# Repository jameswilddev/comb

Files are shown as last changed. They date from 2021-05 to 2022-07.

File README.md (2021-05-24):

# Comb

A low parts, low cost, low complexity game board compatible with some arcade cabinets.  So named as the PCB somewhat resembles a comb.

## Contents

- [Comb Arcade Breakout Board](./src/comb-arcade-breakout-board/readme.md) - A simple PCB which breaks the arcade connector out to 2.54mm pin headers or sockets, for prototyping purposes.
- [Comb Board](./src/comb-board/readme.md) - A game PCB which fits directly into the arcade connector.
- [Engine][./src/engine/readme.md] - A simplistic games engine.
- [Games][./src/games/readme.md] - A collection of small example games.

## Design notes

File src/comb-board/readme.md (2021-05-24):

# [Comb](../../README.md) > Board

This is a game PCB which fits directly into the arcade connector.

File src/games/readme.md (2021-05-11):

# [Comb](../../README.md) > Games

This is a collection of small example games.

## Contents

- [Deathmatch Tennis](./deathmatch-tennis/readme.md) - A silly tennis game.

## File Structure

### configuration.asm

Use this file to override any default configuration set by the engine, such as [timings](../engine/timings/defaults.asm) or [pin mappings](../engine/pin-mappings/defaults.asm).

### declarations.asm

Use this file to declare any macros or constants which will be needed in your event handlers.

### on/reset.asm

Executed during start-up.  Initialize any SRAM containing game state here.

### on/frame.asm

Executed once per frame.  Advance game state here.  All registers are to be considered clobbered.  Stability problems may occur should an excessive amount of time be taken (TODO: how many cycles?).

### on/row.asm

Executed once per display row.  All registers are to be considered clobbered.  Configure registers so that the [blitter](../engine/interrupt/handler/active-video.asm) can output pixel data during the next active video region.  Stability problems may occur should an excessive amount of time be taken (TODO: how many cycles?).

### on/sample.asm

Executed at approximately 15kHz (may occur during an interrupt during the frame event handler).  Output the next audio sample.  Stability problems may occur should an excessive amount of time be taken (TODO: how many cycles?).

### data.asm

Use this file to declare any static data which should be included in program memory.  This will be included at the end of the binary.

## Building

To build these games, use Make:

```
make dist/deathmatch-tennis.hex
```

### Dependencies

- A Unix-like environment.
- Make.
- AVRA on the PATH.
- Aseprite on the PATH.
- NodeJS 14.x or newer.

## Deployment

The Makefile also includes some helper targets for configuring the ATMega328P.  These are only intended to be used with a SPI programmer directly connected to the ATMega328P.  An Arduino can be used as a programmer if the ArduinoISP sketch is uploaded to it; check the sketch's documentation for details on connecting the Arduino to the ATMega328P.

### Setting fuses

To set the fuses:

```
make set-fuses PROGRAMMER=avrisp BAUD=19200 PART=M328P PORT=/dev/ttyS3
```

Ensure that a 16mHz crystal is connected with load capacitors first as the fuse configuration will switch from the internal RC oscillator to a crystal oscillator; which will cause it to lock up if no such crystal is attached.

### Flashing a game

To flash a game:

```
make deploy-deathmatch-tennis PROGRAMMER=avrisp BAUD=19200 PART=M328P PORT=/dev/ttyS3
```

### Dependencies

- A Unix-like environment.
- Make.
- AVRDUDE on the PATH.

### Electrical considerations

The default pin mapping avoids using the SPI pins for inputs as activating an arcade input connects it directly to ground - which could damage the ATMega328P and/or the connected programmer.  Conveniently, the SPI pins overlap with the pins needed for video output, which does not pose such a short circuit hazard.

If a bootloader is used, PD0/PD1 will be used instead (TX/RX).  Do not short these pins to ground during programming.

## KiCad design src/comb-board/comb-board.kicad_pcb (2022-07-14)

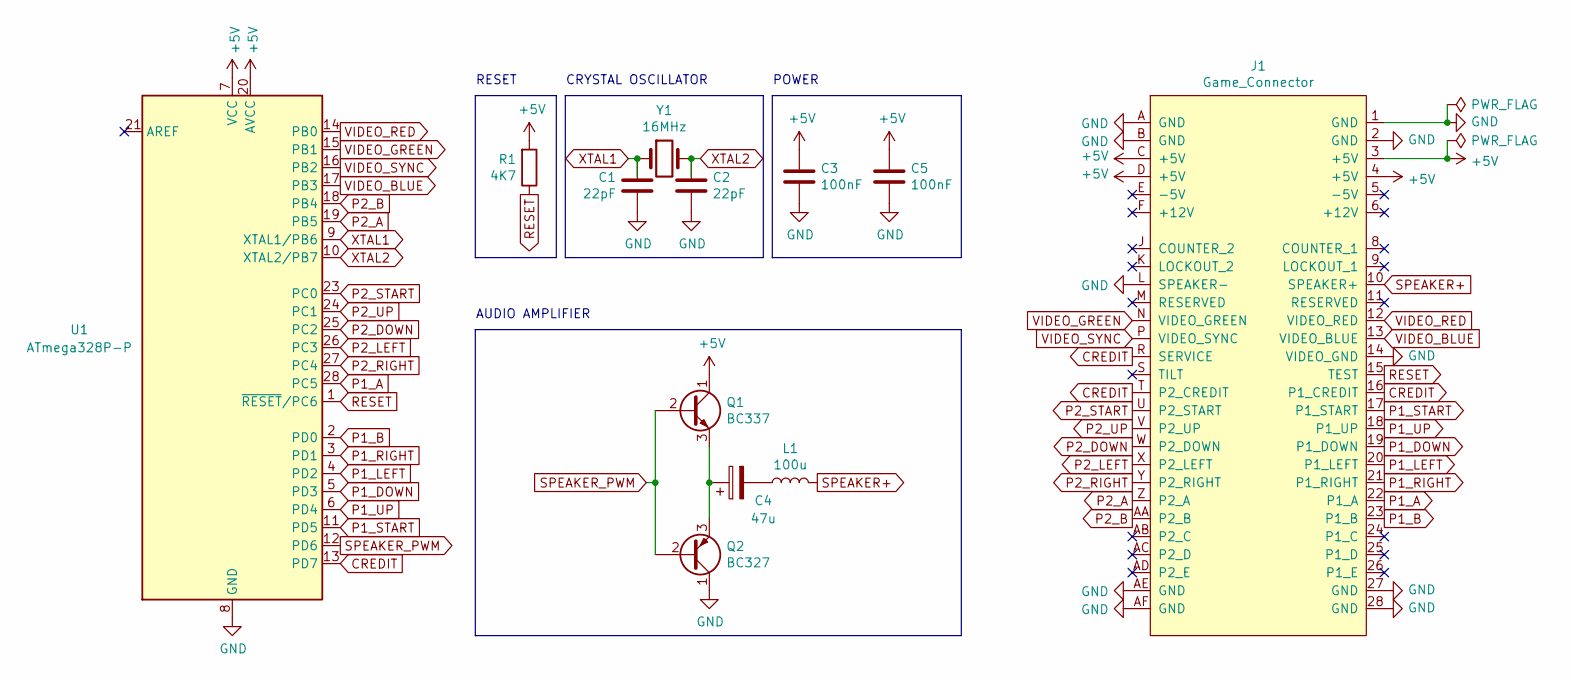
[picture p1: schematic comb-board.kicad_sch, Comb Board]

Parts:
C1, C2: 22pF; C_Disc_D3.0mm_W1.6mm_P2.50mm
C3, C5: 100nF; C_Disc_D3.0mm_W1.6mm_P2.50mm
C4: 47u; CP_Radial_D6.3mm_P2.50mm
J1: Game_Connector; Edge_Connector
L1: 100u; L_Radial_D7.5mm_P5.00mm_Fastron_07P
Q1: BC337; TO-92_Inline
Q2: BC327; TO-92_Inline
R1: 4K7; R_Axial_DIN0204_L3.6mm_D1.6mm_P7.62mm_Horizontal
U1: ATmega328P-P; DIP-28_W7.62mm
Y1: 16MHz; Crystal_HC49-4H_Vertical

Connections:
+5V: C3.2, C5.2, J1.3 (+5V), J1.4 (+5V), J1.C (+5V), J1.D (+5V), Q1.1 (C), R1.2, U1.7 (VCC), U1.20 (AVCC)
CREDIT: J1.16 (P1_CREDIT), J1.R (SERVICE), J1.T (P2_CREDIT), U1.13 (PD7)
GND: C1.1, C2.1, C3.1, C5.1, J1.1 (GND), J1.2 (GND), J1.14 (VIDEO_GND), J1.27 (GND), J1.28 (GND), J1.A (GND), J1.AE (GND), J1.AF (GND), J1.B (GND), J1.L (SPEAKER-), Q2.1 (C), U1.8 (GND), U1.22 (GND)
unnamed: C4.1, Q1.3 (E), Q2.3 (E)
unnamed: C4.2, L1.1
P1_A: J1.22 (P1_A), U1.28 (PC5)
P1_B: J1.23 (P1_B), U1.2 (PD0)
P1_DOWN: J1.19 (P1_DOWN), U1.5 (PD3)
P1_LEFT: J1.20 (P1_LEFT), U1.4 (PD2)
P1_RIGHT: J1.21 (P1_RIGHT), U1.3 (PD1)
P1_START: J1.17 (P1_START), U1.11 (PD5)
P1_UP: J1.18 (P1_UP), U1.6 (PD4)
P2_A: J1.Z (P2_A), U1.19 (PB5)
P2_B: J1.AA (P2_B), U1.18 (PB4)
P2_DOWN: J1.W (P2_DOWN), U1.25 (PC2)
P2_LEFT: J1.X (P2_LEFT), U1.26 (PC3)
P2_RIGHT: J1.Y (P2_RIGHT), U1.27 (PC4)
P2_START: J1.U (P2_START), U1.23 (PC0)
P2_UP: J1.V (P2_UP), U1.24 (PC1)
RESET: J1.15 (TEST), R1.1, U1.1 (~RESET/PC6)
SPEAKER+: J1.10 (SPEAKER+), L1.2
SPEAKER_PWM: Q1.2 (B), Q2.2 (B), U1.12 (PD6)
VIDEO_BLUE: J1.13 (VIDEO_BLUE), U1.17 (PB3)
VIDEO_GREEN: J1.N (VIDEO_GREEN), U1.15 (PB1)
VIDEO_RED: J1.12 (VIDEO_RED), U1.14 (PB0)
VIDEO_SYNC: J1.P (VIDEO_SYNC), U1.16 (PB2)
XTAL1: C1.2, U1.9 (XTAL1/PB6), Y1.1
XTAL2: C2.2, U1.10 (XTAL2/PB7), Y1.2

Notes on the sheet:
RESET
AUDIO AMPLIFIER
CRYSTAL OSCILLATOR
POWER

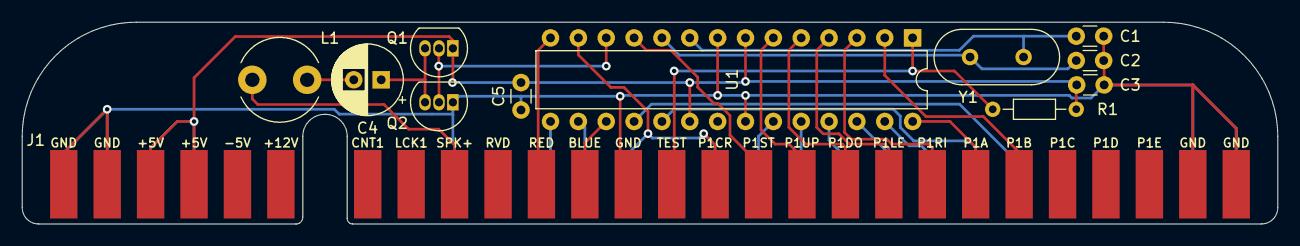
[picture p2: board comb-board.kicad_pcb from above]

Board: 2 copper layers, 114.5 x 18.4 mm, 12 parts (0 on the bottom side), 28 nets.

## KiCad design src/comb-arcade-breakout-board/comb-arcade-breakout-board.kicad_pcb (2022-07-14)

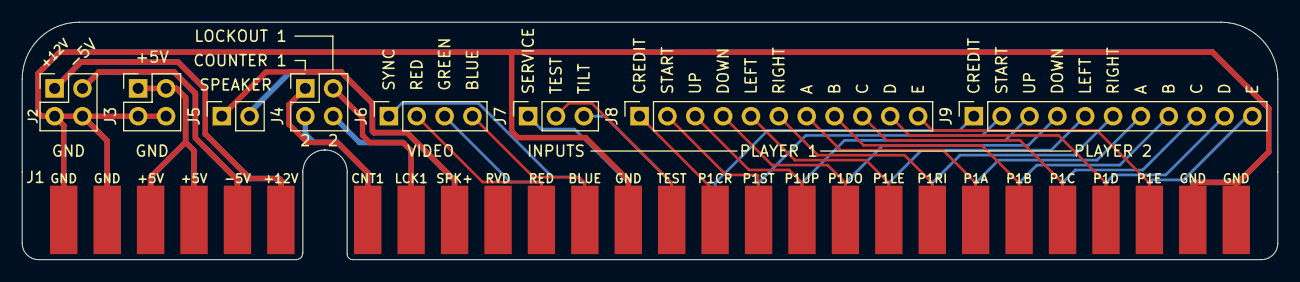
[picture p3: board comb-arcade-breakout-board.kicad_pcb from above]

Board: 2 copper layers, 114.5 x 21.7 mm, 9 parts (0 on the bottom side), 39 nets.

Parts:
J1: Game_Connector; Edge_Connector
J2: PWR_DANGEROUS; PinSocket_2x02_P2.54mm_Vertical
J3: PWR_SAFE; PinSocket_2x02_P2.54mm_Vertical
J4: COIN_SLOTS; PinSocket_2x02_P2.54mm_Vertical
J5: SPEAKER; PinSocket_1x02_P2.54mm_Vertical
J6: VIDEO; PinSocket_1x04_P2.54mm_Vertical
J7: MISC_INPUTS; PinSocket_1x03_P2.54mm_Vertical
J8: P1; PinSocket_1x11_P2.54mm_Vertical
J9: P2; PinSocket_1x11_P2.54mm_Vertical

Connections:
+5V: J1.3, J1.4, J1.C, J1.D, J3.1, J3.3
+12V: J1.6, J1.F, J2.1
-5V: J1.5, J1.E, J2.3
COUNTER_1: J1.8, J4.1
COUNTER_2: J1.J, J4.2
GND: J1.1, J1.2, J1.14, J1.27, J1.28, J1.A, J1.AE, J1.AF, J1.B, J2.2, J2.4, J3.2, J3.4
LOCKOUT_1: J1.9, J4.3
LOCKOUT_2: J1.K, J4.4
P1_A: J1.22, J8.7
P1_B: J1.23, J8.8
P1_C: J1.24, J8.9
P1_CREDIT: J1.16, J8.1
P1_D: J1.25, J8.10
P1_DOWN: J1.19, J8.4
P1_E: J1.26, J8.11
P1_LEFT: J1.20, J8.5
P1_RIGHT: J1.21, J8.6
P1_START: J1.17, J8.2
P1_UP: J1.18, J8.3
P2_A: J1.Z, J9.7
P2_B: J1.AA, J9.8
P2_C: J1.AB, J9.9
P2_CREDIT: J1.T, J9.1
P2_D: J1.AC, J9.10
P2_DOWN: J1.W, J9.4
P2_E: J1.AD, J9.11
P2_LEFT: J1.X, J9.5
P2_RIGHT: J1.Y, J9.6
P2_START: J1.U, J9.2
P2_UP: J1.V, J9.3
SERVICE: J1.R, J7.1
SPEAKER+: J1.10, J5.1
SPEAKER-: J1.L, J5.2
TEST: J1.15, J7.2
TILT: J1.S, J7.3
VIDEO_BLUE: J1.13, J6.4
VIDEO_GREEN: J1.N, J6.3
VIDEO_RED: J1.12, J6.2
VIDEO_SYNC: J1.P, J6.1

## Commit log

2021-05-02 Add shared footprints and symbols.
2021-05-02 Add arcade breakout board.
    [comb-arcade-breakout-board.kicad_pcb, comb-arcade-breakout-board.sch]
2021-05-02 Do not commit Gerber files.
2021-05-02 First attempt at KiCAD exports in CI.
2021-05-02 Fix misalignements on comb PCB.
    [comb-arcade-breakout-board.kicad_pcb]
2021-05-02 Adjust label.
    [comb-arcade-breakout-board.kicad_pcb]
2021-05-02 Fix label cropping.
    [comb-arcade-breakout-board.kicad_pcb]
2021-05-09 Move PCB design under a src directory.
    [comb-arcade-breakout-board.kicad_pcb, comb-arcade-breakout-board.sch]
2021-05-24 Rename FREE CREDIT to SERVICE.
    [comb-arcade-breakout-board.kicad_pcb, comb-arcade-breakout-board.sch]
2021-05-24 Initial game board design.
    [comb-board.kicad_pcb, comb-board.sch]
2022-07-14 Upgrade KiCAD.
2022-07-14 Fix DRC.
    [comb-arcade-breakout-board.kicad_pcb, comb-arcade-breakout-board.kicad_sch, comb-board.kicad_pcb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]
